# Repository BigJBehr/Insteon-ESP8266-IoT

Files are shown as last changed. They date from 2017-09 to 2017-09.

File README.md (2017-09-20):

Insteon ESP8266 Lighting Controller

# Insteon ESP8266 IoT

## Why I did this:
Home automation is a hot topic these days. It covers everything from window and door sensors to WiFi enabled thermostats to remote control of lights and appliances. I use Insteon devices to control some of the lights in my house and a ceiling fan/light in my bedroom. I originally chose Insteon because it is backward compatible with my older X10 devices. With the inclusion of an Insteon Hub, you can install the Insteon app on your Android or IOS device and control your Insteon devices with your phone or tablet. Insteon is also compatible with the Amazon Echo Dot, a.k.a Alexa. With Insteon and Alexa you can issue voice commands to control your Insteon devices. Very cool. So why would you need yet another way to control your Insteon devices ? The reasons are that Alexa is expensive and does not always work! Your local Amazon Echo recognizes the key phrase “Alexa” and then uses your Internet connection to forward your voice command to an Amazon server for processing. The reply is a digital command sequence that your Alexa forwards to the Insteon Hub. The Insteon Hub then performs the magic. Sometimes Alexa tells me that my Insteon Hub cannot be found or that she is having trouble connecting to the Amazon servers. The end result is that my voice commands do not work. So I have to find my phone or a tablet, wait for it to boot up and then issue the command using the Insteon app. This can be a hassle if you just got into bed and want to turn off the light. You have to get back up and locate an Android device. Ugh.

It would be so much nicer if you had a simple WiFi device with switches that could be programmed to turn on/off your Insteon devices on your bedside table. It would also be great if said device did not rely on having to send messages over the Internet to remote servers to send commands to your local Insteon Hub. This is exactly what I have designed. A simple, low cost, ESP8266 powered IoT device that sends commands to your Insteon Hub, using your local WiFi and wired network. Internet is not required and no outside servers are used.
I designed my Insteon Switch Box to have up to eight pushbutton switches. Each switch can be programmed to turn on or off one Insteon device or scene. A switch may also be programmed to read the state of an Insteon device and then issue a command to change the state. The result is one switch that with one press turns on an Insteon device and a second press turns off the same device. I use an Insteon Fanlinc device to control a ceiling fan in my bedroom. A Fanlinc has two sections. One section controls the light and the other controls the fan. The fan can have three speeds and the light is dimmable. Alexa cannot work directly with an Insteon Fanlinc. In order to use a Fanlinc with Alexa you must create scenes. One scene for the light and one scene for each of the fan speeds. Because scenes are either on or off, Alexa cannot dim the Fanlinc’s light. My Insteon Switch box can send commands to the Insteon Hub to turn on or off or dim the Fanlinc’s light and to control the fan without the need for scenes. This is an improvement over what Alexa can do. My Insteon Switch box was not designed to control a thermostat or listen for door or window sensors. However, with Insteon On/Off plug-in modules that use a relay to turn on/off the plugged in object, it is possible to control drapes or a coffee maker, toaster or electric kettle. You merely have to press a button when you get out of bed. When you exit the shower, your coffee will be ready. All without waking up your mate by talking to Alexa.

## What You will Need:
-	Any ESP8266-12 module or board with an ESP8266-12 module on it. 
-	USB-to-Serial bridge with RTS and DTR unless the ESP8266 board has it built-in.
-	5V, 2A power supply.
-	Power Jack that mates with the power supply.
-	Eight 10K resisters
-	Eight Pushbutton Switches
-	Custom Circuit Board or hand-wired circuit board
-	See individual Bills of Materials for complete parts list.

### Software apps and online services:
-	Arduino IDE, version 1.8.0 or higher
-	ESP8266 Plug-in for Arduino
-	Optional, OpenSCAD

### Hand tools and fabrication machines:
-	Soldering iron
-	Solder, preferably with no clean flux
-	Diagonal cutters
-	Screwdriver
-	Optional, 3D printer

### The Files
- Insteon
  - This folder has the ESP8266 Arduino source code for this project.
- EagleInsteonBoard.zip
  - Zip archive with all the files required to have your own custom circuit boards made.
- Schematic.pdf
  - Pdf version of the Eagle schematic of my custom circuit board.
- 3D Printed Parts
  - This folder contains the OpenScad source file and .stl files for 3D printing all of the case parts.
- Insteon ESP8266 IoT.pdf
  - Pdf file about this project. It has pictures of my custom circuit board, BOMs for each build and detailed information on what to change in the source code to configure it for your Insteon devices and home network.

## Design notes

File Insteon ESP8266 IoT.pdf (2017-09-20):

Insteon ESP8266 IoT
What You will Need:
Any ESP8266-12 module or board with an ESP8266-12 module on it.
USB-to-Serial bridge with RTS and DTR unless the ESP8266 board has it built-in.
5V, 2A power supply.
Power Jack that mates with the power supply.
Eight 10K resisters
Eight Pushbutton Switches
Custom Circuit Board or hand-wired circuit board
See individual Bills of Materials for complete parts list.

Software apps and online services:
Arduino IDE, version 1.8.0 or higher
ESP8266 Plug-in for Arduino
Optional, OpenSCAD

Hand tools and fabrication machines: Soldering iron
Solder, preferably with no clean flux Diagonal cutters
Screwdriver
Optional, 3D printer

Why I did this:
Home automation is a hot topic these days. It covers everything from window and door sensors to WiFi enabled thermostats to remote control of lights and appliances. I use Insteon devices to control some of the lights in my house and a ceiling fan/light in my bedroom. I originally chose Insteon because it is backward compatible with my older X10 devices. With the inclusion of an Insteon Hub, you can install the Insteon app on your Android or IOS device and control your Insteon devices with your phone or tablet. Insteon is also compatible with the Amazon Echo Dot, a.k.a Alexa. With Insteon and Alexa you can issue voice commands to control your Insteon devices. Very cool. So why would you need yet another way to control your Insteon devices ? The reasons are that Alexa is expensive and does not always work! Your local Amazon Echo recognizes the key phrase “Alexa” and then uses your Internet connection to forward your voice command to an Amazon server for processing. The reply is a digital command sequence that your Alexa forwards to the Insteon Hub. The Insteon Hub then performs the magic. Sometimes Alexa tells me that my Insteon Hub cannot be found or that she is having trouble connecting to the Amazon servers. The end result is that my voice commands do not work. So I have to find my phone or a tablet, wait for it to boot up and then issue the command using the Insteon app. This can be a hassle if you just got into bed and want to turn off the light. You have to get back up and locate an Android device. Ugh.

It would be so much nicer if you had a simple WiFi device with switches that could be programmed to turn on/off your Insteon devices on your bedside table. It would also be great if said device did not rely on having to send messages over the Internet to remote servers to send commands to your local Insteon Hub. This is exactly what I have designed. A simple, low cost, ESP8266 powered IoT device that sends commands to your Insteon Hub, using your local WiFi and wired network. Internet is not required and no outside servers are used.

I designed my Insteon Switch Box to have up to eight pushbutton switches. Each switch can be programmed to turn on or off one Insteon device or scene. A switch may also be programmed to read the state of an Insteon device and then issue a command to change the state. The result is one switch that with one press turns on an Insteon device and a second press turns off the same device. I use an Insteon Fanlinc device to control a ceiling fan in my bedroom. A Fanlinc has two sections. One section controls the light and the other controls the fan. The fan can have three speeds and the light is dimmable. Alexa cannot work directly with an Insteon Fanlinc. In order to use a Fanlinc with Alexa you must create scenes. One scene for the light and one scene for each of the fan speeds. Because scenes are either on or off, Alexa cannot dim the Fanlinc’s light. My Insteon Switch box can send commands to the Insteon Hub to turn on or off or dim the Fanlinc’s light and to control the fan without the need for scenes. This is an improvement over what Alexa can do. My Insteon Switch box was not designed to control a thermostat or listen for door or window sensors. However, with Insteon On/Off plug-in modules that use a relay to turn on/off the plugged in object, it is possible to control drapes or a coffee maker, toaster or electric kettle. You merely have to press a button when you get out of bed. When you exit the shower, your coffee will be ready. All without waking up your mate by talking to Alexa.

The remainder of this document will detail how to build one of these for yourself and how to configure the software so it will work with your Insteon devices. There is also some small lessons in writing ‘C’ code.

How to build one:
I designed a custom PCB for this project. All the files can be downloaded from https://github.com/BigJBehr/Insteon-ESP8266-IoT. There is a pdf of the schematic and Eagle files to make your own circuit board. If you have worked with the ESP8266 then you are aware that it comes in a dizzying array of forms. From bare modules that require support circuits to breadboard friendly boards with all required support circuits and a USB-to-serial bridge. The board that I designed for this project can accept the ESP8266 in four different forms and has pads to add any support circuits required by the ESP8266 you chose to use. My board does not have a USB-to-Serial bridge on board. If that is required there is a header to attach one. Your USB-to-Serial bridge must have RTS and DTR in order to program the ESP8266. Of course, you are free to handwire the switches to the ESP8266-12 of your choice. The four ESP8266 forms supported by my board are;

ESP8266-12 module

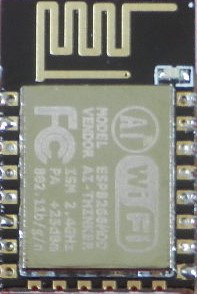
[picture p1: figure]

The least expensive ESP8266, but requires the most support. My board has pads for a 3.3V regulator and the ‘auto-reset’ circuit used for programming. You will need a USB-to-Serial bridge with RTS and DTR.

Bill of Materials
Quantity | Reference Numbers | Description
1 | SOC1 | ESP8266-12 module
8 | SW1 – SW8 | Pushbutton switches, four leads, 7x4mm spacing
10 | R1, R3 – R11 | 10K , surface mount resistors, 1206
1 | R2 | 470 , surface mount resistor, 1206
2 | R12, R13 | 1K , surface mount resistors, 1206
2 | R14, R15 | 4.7K , surface mount resistors, 1206
1 | VR1 | AS1117-3.3V regulator, SOT-223
2 | Q1, Q2 | MMBT2222A transistor, TO-23
2 | C1, C2 | 10uf, 16V, Tantalum, capacitors, 1206, size A
1 | J5 | 3 pin right angle, male header

1 | J8 | 6 pin right angle, male header

ESP8266-12 Witty Board

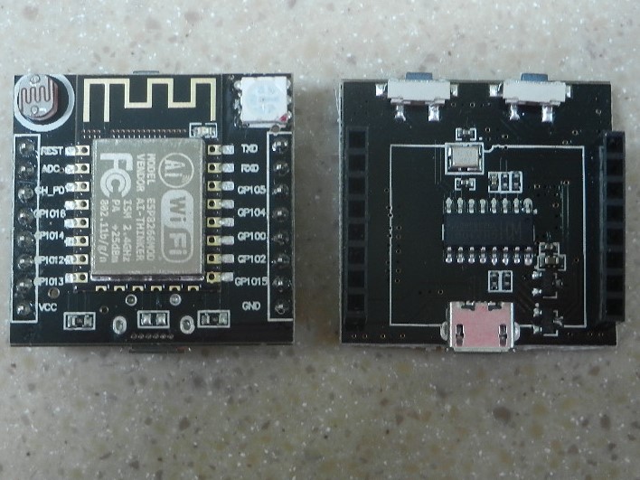
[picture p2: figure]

This is actually two boards that mate together. If you use this you will only need the top board that actually contains the ESP8266 and the 3.3V regulator. You can program the ESP8266 while attached to the lower board it came with and then mount it to your board or you can program it in place by using jumpers to connect to the lower board or adding the ‘auto-reset’ circuit and using a USB-to-Serial bridge. Do not throw away the lower board. You can always use it as a USB-to-Serial bridge. Just be aware that it provides 5V signals, not 3.3V signals like most USB-to-Serial bridges. The Witty board does not require the pulldowns on GPIO15 and the analog input as these parts are on the Witty board. You can also eliminate the pullups on Reset and GPIO0 (SW7) for the same reason.

Bill of Materials (BOM)
Quantity | Reference Numbers | Description
1 Witty ESP8266-12 board
2 | J1, J2 | 8 pin female socket headers, optional
8 | SW1 – SW8 | Pushbutton switches, four leads, 7x4mm spacing
10 | R3 – R9, R11 | 10K , surface mount resistors, 1206
2 | R12, R13 | 1K , surface mount resistors, 1206
1 | VR1 | AS1117-3.3V regulator, SOT-223
2 | Q1, Q2 | MMBT2222A transistor, TO-23
2 | C1, C2 | 10uf, 16V, Tantalum, capacitors, 1206, size A
1 | J5 | 3 pin right angle, male header
1 | J8 | 6 pin right angle, male header

Note:
If you do not intend to program the ESP8266 Witty board in circuit then you can eliminate; Q1, Q2, J8, R12 and R13. If you solder the Witty board in place then use the holes for J1 and J2 and you can eliminate J1 & J2. Power can be applied using the micro USB connector on the bottom of the Witty board with the ESP8266 or can be wired to J5 or J8. You can eliminate J5 if you intend to use J8 or the micro USB connector.

GeekCreit, DOIT, ESP8266-12 DevKit board

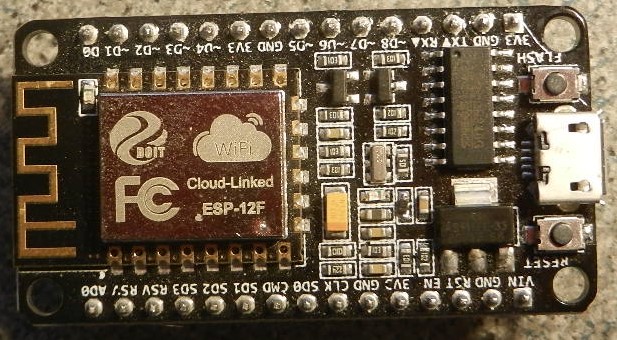
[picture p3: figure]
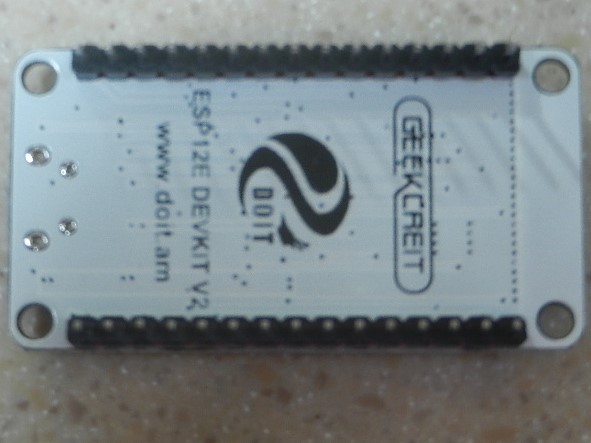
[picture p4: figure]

This is a single board that has everything onboard to program the ESP8266. There is a micro USB connector and an onboard USB-to-Serial bridge. No support circuits are required to use this board. Boards like this are also known as NodeMcu boards. These boards come in two widths, wide and narrow. My circuit board is laid out to accept the narrower boards. Look for one that has pin spacing of 0.9 inches. The original NodeMcu boards have 1.2 inch spacing and will not fit.

Bill of Materials
Quantity | Reference Numbers | Description
1 GeekCreit, DoIt ESP8266-12 board
2 | J3, J4 | 15 pin female socket headers, optional
8 | SW1 – SW8 | Pushbutton switches, four leads, 7x4mm spacing
10 | R3 – R9, R11 | 10K , surface mount resistors, 1206
1 | J5 | 3 pin right angle, male header, optional

Note:
If you solder the GeekCreit, DoIt board in place then you can eliminate J3 & J4. You can power the system using the micro USB connector on the GeekCreit board or using J5.

Sparkfun ESP8266 Thing Dev board

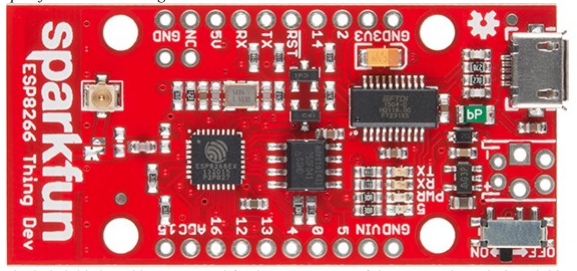
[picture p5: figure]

I included this board because Sparkfun is a co-sponsor of the contest that I designed this project for. Unfortunately, the sponsors did not like my idea well enough to provide me with a free Sparkfun ESP8266 Thing Dev board. The Sparkfun board has all of the required support circuits already on it, including the USB-to-Serial bridge.

Bill of Materials
Quantity | Reference Numbers | Description
1 Sparkfun ESP8266 Thing Dev board
2 | J6, J7 | 10 pin female socket headers, optional
2 10 pin male headers
8 | SW1 – SW8 | Pushbutton switches, four leads, 7x4mm spacing
10 | R3 – R9, R11 | 10K , surface mount resistors, 1206
1 | J5 | 3 pin right angle, male header, optional

Note:
If you solder the Sparkfun ESP8266 Thing Dev board in place then you can eliminate J6 & J7. You can power the system using the micro USB connector on the Sparkfun ESP8266 Thing Dev board or using J5. The two 10 pin male headers are soldered to the bottom of the Sparkfun ESP8266 Thing Dev board (they should come with the board).

My custom circuit board has places to mount eight pushbutton switches and provides pads for a 10K pullup for each switch. The pullups are required due to the ESP8266 not having internal pullups on the GPIO pins. All of the GPIO pins except the analog pin, GPIO15, Tx and Rx are used for the pushbutton switches. The analog input and GPIO15 have pulldowns wired to them and Rx has a pullup. No pins are left floating. Always a good thing to do. Of course, you are free to handwire your own board. Then you can use whatever ESP8266 board that you have available. You can leave out the 3.3V regulator and ‘auto-reset’ circuits if the board you use does not require them. Mount the ESP8266 board of your choice with the antenna oriented as indicated on the circuit board. Use the set of holes or pads that fit the board that you are using. The mounting holes in the corners are sized to accept 3mm, 4-40 or 6-32 hardware.

I prefer to assemble boards from the lowest height components to the tallest components. Therefore I usually start with the surface mount resistors, transistors, capacitors and regulators. Then comes the ESP8266 module. Last would be the headers and sockets. I built my boards with right angle male headers facing inward to reduce the overall height and length of the finished board. The pushbutton switches are intended to be mounted on the bottom side of the board. I have included pictures of assembled boards with different ESP8266 boards attached. The ESP8266 boards were not soldered down. They are in place to show location and orientation. They were paid scale for their modeling work.

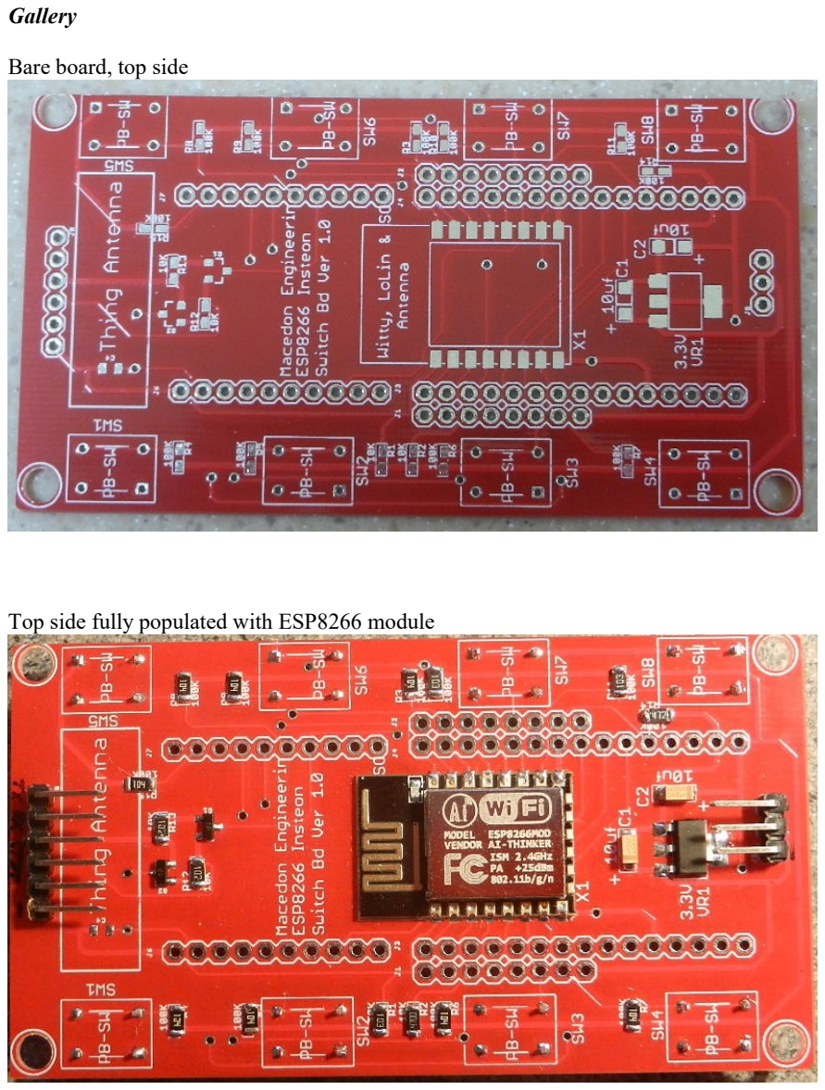
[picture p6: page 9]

Gallery

Bare board, top side

Top side fully populated with ESP8266 module

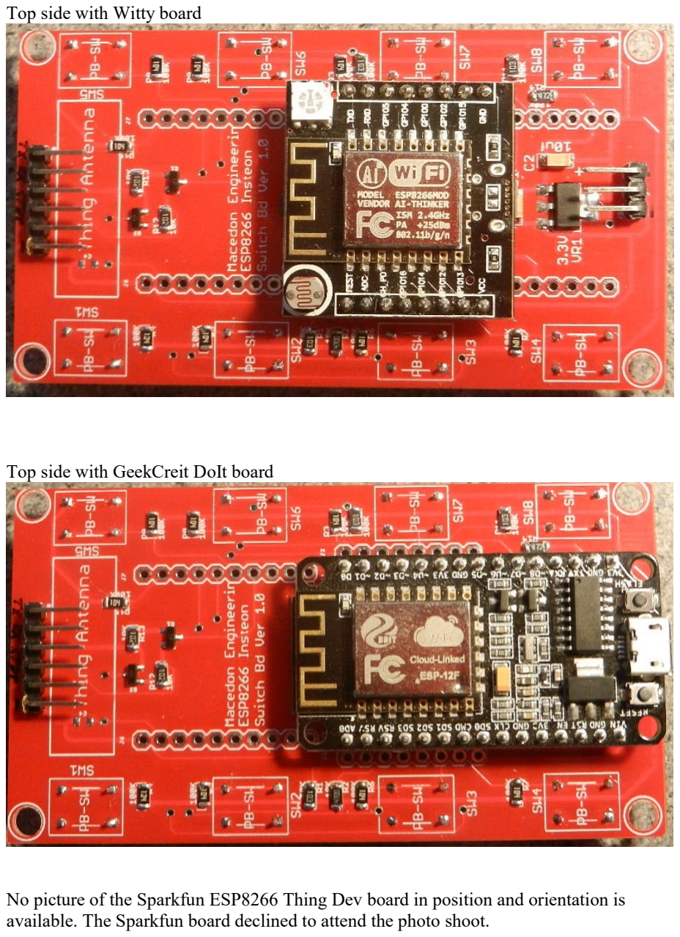
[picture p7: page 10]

Top side with Witty board

Top side with GeekCreit DoIt board

No picture of the Sparkfun ESP8266 Thing Dev board in position and orientation is available. The Sparkfun board declined to attend the photo shoot.

Bottom populated with pushbutton switches

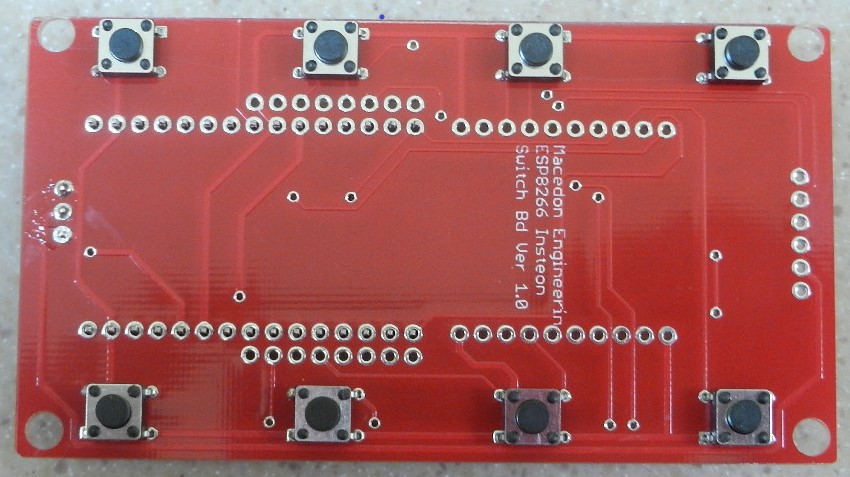
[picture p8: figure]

How it works:
The ESP8266 at the heart of the Insteon Switch box debounces the switches and looks for a switch pressed. When it detects that a switch has been pressed it looks up what has been programmed for that switch to do and then creates a control message for the Insteon Hub. The message is sent to the Hub, which converts the message into a control command and forwards it to the targeted Insteon device. Any replies from the targeted Insteon device are sent back to the Hub and the Hub then sends the reply back to ESP8266 using the Insteon Hub message format. The reply is parsed and the relevant data is stored. The Internet is not used. Everything is done over your local network.

How to configure the firmware for your Insteon devices:

There are a lot of websites providing detailed instructions on how to setup the Arduino IDE, compile a program and upload it as well as how to install the ESP8266 plug-in. I am not going to repeat that information here. Just Google it.

I have defined a ‘C’ structure named TSwitch, that contains all the information needed for one pushbutton switch. The structure is as follows;

Typedef struct {
byte | pin; | // GPIO pin number that the switch is wired to
int16_t | state; | // the last known state of the Insteon device
uint32_t | debounce; | // switch debouncer bit array
ActionPtr | action; | // pointer to the action function assigned to the switch
char | *devId; | // pointer to the device ID string of the Insteon device

char | *cmd2; | // pointer to the cmd2 string to send for status requests
char | *cmdOn; | // pointer to the on command string
char | *cmdOff; | // pointer to the off command string
} TSwitch;

An array of eight TSwitch structures is used to hold the information for each switch. If you build one of these for yourself you will need to replace the data in some of the fields of the TSwitch structure for how you would like your switches to work and for the Insteon devices and scenes that you want to control. Each Insteon device has a label on it with its unique Insteon ID. I have a series of statements where I define a meaningful to me name for each Insteon device ID. You can find these in the code as;

#define Kitchen “339EFC”

Kitchen is the meaningful name, “339EFC” is the Insteon device ID.

The #define makes this a ‘C’ preprocessor macro. This means that wherever Kitchen is found in the source code the ‘C’ preprocessor will substitute “339EFC”. “339EFC” is the Insteon ID string converted from the dot format on the label (33.9E.FC). I also have some #define statements that define the scene Ids that I might use. Scene Ids are two digit number strings such as “10” for scene number ten or “07” for scene number seven. You can get the scene numbers and Insteon Ids from the Insteon app on your phone or tablet. There are a bunch of #define statements that define the command strings that can be used. All of the command strings are prefixed with Cmd followed by a descriptive name. For example;

#define CmdOn | “11FF” | // command to turn on a device to full brightness

You will need to change the #define statements that define the Insteon Ids and scene numbers for the devices and scenes that you use. The #define statements for the commands should not be changed.

There is a statement; #define PINMASK 0x00000FFF
This statement defines the number of bits that are used to debounce a pushbutton switch. If the buttons that you use have more than 12mS of bounce then you should increase the number of bits in the mask. If you use all 32 bits and require more time then you should change the 1mS delay in the main loop to two or more milliseconds and decrease the number of bits accordingly. Twelve bits and 1mS should be adequate for most pushbutton switches.

As I stated earlier, there is an array of eight TSwitch structures, one for each pushbutton switch. A ‘C’ style initializer is defined for the array. This means that a table of entries for initializing the TSwitch array is defined in Flash ROM. The table is copied to the RAM TSwitch array automatically when the program starts up. You have to edit this initializer table to configure what you want the pushbutton switches to do and what Insteon devices/scenes each pushbutton will work with. The initializer is of the form;

{SWx, UnknownState, 0, action-to-take, device Id/scene, Cmd2, CmdOn, Cmdoff}

The individual initializers are separated by a comma (‘,’) and the whole group of eight initializers is wrapped in a pair of curly braces (‘{‘ ‘}’). This is just the way that the ‘C’ programming language does things. There must be one initializer for each entry in the array or the compiler will complain. If you leave out a curly brace or a comma the compiler will complain. That is just how compilers are, always complaining that you left something out. The pushbutton switches are arranged in the same numerical order that they are in the hardware, so SW1 in the software is SW1 on the board, is array[0]. I advise against changing the order of the switches. The first three entries in the initializer should remain unchanged. They represent the GPIO pin the pushbutton switch is wired to, the state of the Insteon device (unknown), and the state of the debouncer. The forth value is a pointer to the ‘C’ function that will be called when the switch is pressed. There are a number of action functions defined. You should choose the one that does what you want the pushbutton to do. If you are not using the pushbutton then set the action field to NULL (all caps). This will tell the code to ignore this pushbutton. The action functions are; actionToggle, actionOn, actionOff, actionFanSpeed.

actionToggle reads the current state of the Insteon device whose ID is in the devId field of the associated TSwitch structure and then issues a command to change to the opposite state. Use actionToggle to create a button that will turn something on when pressed and turn it off when pressed again. The cmdOn and cmdOff fields of the associated TSwitch structure are used to get the on and off commands. If the Insteon device being used is dimmable then you could use the CmdHalf command in place of CmdOn. This would cause the light to toggle between half brightness and off.

actionOn simply sends whatever command is in the cmdOn field of the associated TSwitch structure to the Insteon device whose ID is in the devId field of the associated TSwitch structure. Use actionOn when you want a pushbutton to turn an Insteon device on. If you replace the CmdOn with CmdHalf and the Insteon device is dimmable then it would come on at half brightness. If you replaced CmdOn with CmdBrighten then each time you pressed the button the brightness would increase until full brightness is achieved.

actionOff simply sends whatever command is in the cmdOff field of the associated TSwitch structure to the Insteon device whose ID is in the devId field of the associated TSwitch structure. Use actionOff when you want a pushbutton to turn an Insteon device off. If your Insteon device is dimmable then you can substitute CmdHalf to reduce the brightness to half or CmdDim to reduce the brightness in steps until it was fully off. If you used CmdHalf then you will need to use another button to actually turn the device off.

actionFanSpeed is unique in that it reads the current fan speed setting and then ups the speed to the next fan speed setting. The cycle is; off -> low -> medium -> high -> off. ActionFanSpeed does not use the cmdOn and cmdOff fields.

The next field in the initializer (devId) is a ‘C’ style character string that contains the Insteon Id of the device or the scene number that you want to control. I previously talked about the #define values that I setup to provide meaningful names (aliases) for my Insteon Ids. Here I use those names. You should do the same, making meaningful names for your Insteon Ids or simply put the Insteon Id string here as “123456”. Keep In mind that an Insteon device Id will have six characters while a scene number will have two digits (“07”).

The next field in the initializer is the cmd2 field. This field is normally initialized with the value; Cmd2Lights. Change this initializer to Cmd2Fans if you are setting up a pushbutton to work with the fans section of a Fanlinc Insteon device.

The last two fields of the initializer are the cmdOn and cmdOff fields. These fields contain pointers to the defined Insteon command strings. Typically you would put CmdOn in cmdOn and CmdOff in cmdOff. You can put any of the CmdXxxx values in these fields, although CmdStatus, Cmd2Lights and Cmd2Fans should not be used.

One thing to note here, I defined a simple command for CmdOn that turns a light on full brightness. If you have dimmable light controller you can define commands that will turn on your light to a preset brightness. The light on command is “11” the “FF” in the second byte is the brightness level. CmdHalf is defined as “117F”, it will turn your light on to half brightness. You can use any value from “01” to “FF” for the brightness level. Keep in mind that if you send a command for partial brightness to an Insteon device that is not dimmable or a scene then it will turn on at full brightness.

The CmdOnFast and CmdOffFast commands are be used to override the ramp up and ramp down setting in the Insteon app and force the device to full brightness or off without ramping. I do not use these commands because all my dimmable Insteon devices use the default ramping.

There are also #define statements for;
SSID | – change to the ssid of your network
PASSKEY | – change to the WiFi WPA passkey for your network,
HUBUSER | – change to the user ID for your Insteon Hub
HUBPASSWORD | – change to the password for your Insteon Hub
HUBIP | – change to the IP address of your Insteon Hub
HTTPPORT | – you can change this if you change the port number that your
Insteon Hub uses, otherwise this is the default value.

That’s it. Make the changes to the source code, recompile and download it to your ESP8266. I hope that you find it to be a useful addition to how you control your Insteon devices. If you have any problems building one for yourself or need help with the code you may contact me through HacksterIO. I will endeavor to provide as much help as I can.

I bought ten of these boards from a Chinese PCB manufacturer. I built up three. I have seven boards that are unused bare boards. If you would like one, tell me why you deserve a free board and maybe I will send you one.

I have included the Eagle files the board was made from in the GitHub archive. Feel free to have your own boards made. Ten boards cost around $15-$20.00 US and take about 3-4 weeks to arrive in the USA.

I have also designed a 3D printable case for my project board. The design was done using OpenSCAD. I have include the OpenSCAD source code and the .stl file if you would like to print your own. If you design your own case, I would be interested in seeing what you came up with. Send me a picture of the case you designed. My case uses four 3x6mm screws to hold the board to the top of the case. In the OpenSCAD source file there is a variable named SHD that can be changed to make the hole in the bosses correct for other screw sizes. Always use a ¼ inch or 6mm long screw to avoid coming through the top of the case. After printing the parts, clean off all of the easy removal pads. Insert the buttons into the holes in the top, wide part should be inside the case. Screw the circuit board to the underside of the top. Add the power jack to the case bottom. Solder wires to the power jack. Either add crimp pins and a header, or use an IDC header or solder the wires in place of J5 on the circuit board. The top just snaps into the bottom. The fit should be tight enough that it will stay put without any glue. Congratulations, pat yourself on the back and break out the Champagne. You are done.

The .stl file is for a case top, bottom, four bullet top buttons and four flat top buttons. It is very easy to modify the source code to print only the top or bottom or to change the number of bullet top & flat top buttons. I commented out the top and bottom parts and printed some buttons using red and white filament. Everything is done in a modular fashion with the lines following the “$fn=50” to the first “module” statement determining what gets printed. “translate” statements are used to reposition the parts. If you only print buttons then change the “translate” statements to move the buttons to the center of your build platform or where ever you want them.

Here are some pictures of the case assembly.

Power plug assembly

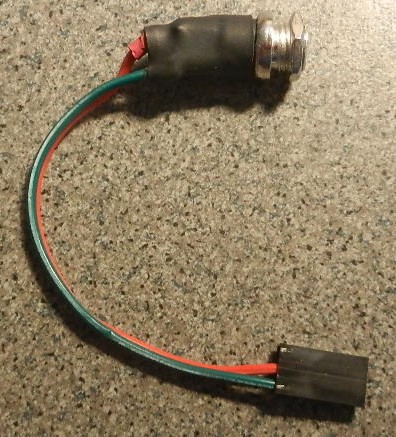
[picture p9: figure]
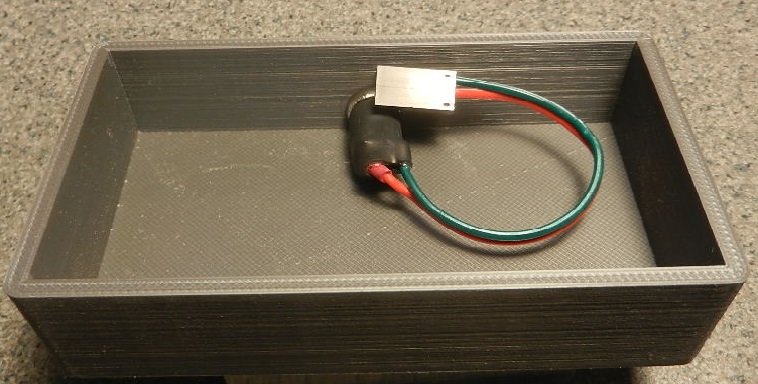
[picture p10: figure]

Case bottom with power plus assembly.

Under side of the case top. Ready for buttons and circuit board.

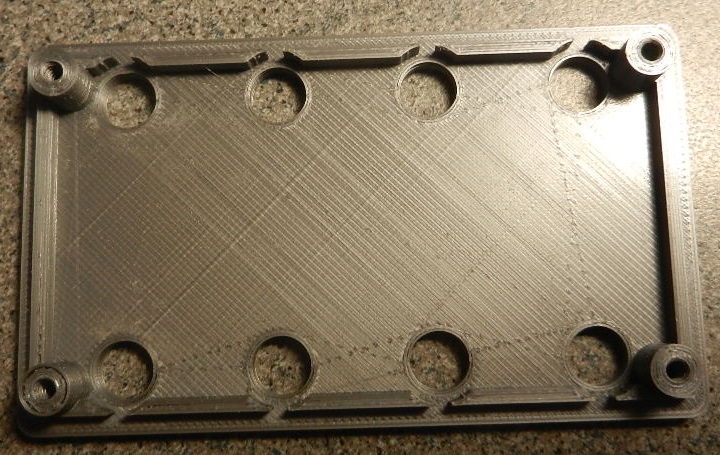
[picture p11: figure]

Case top with buttons inserted. Red buttons are in position for Sw1-Sw3. Notice how the case bottom is used to support the top so that you are not fighting with the buttons.

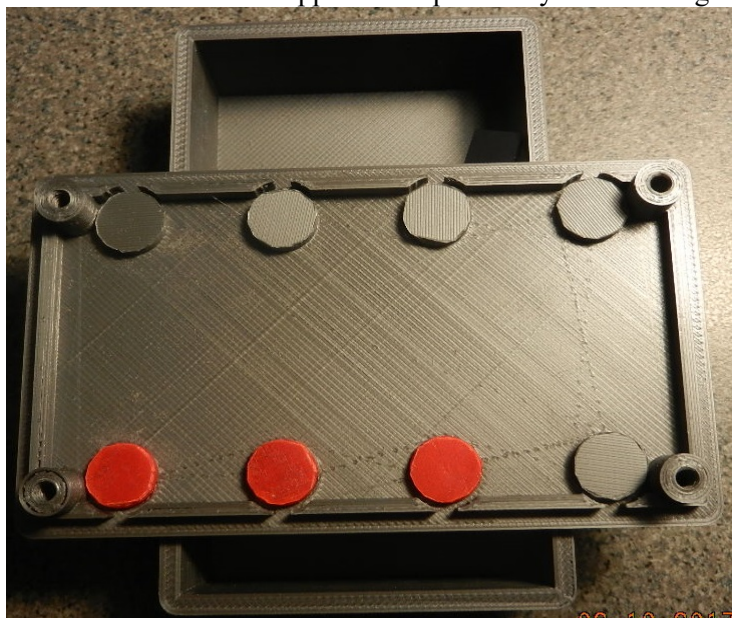
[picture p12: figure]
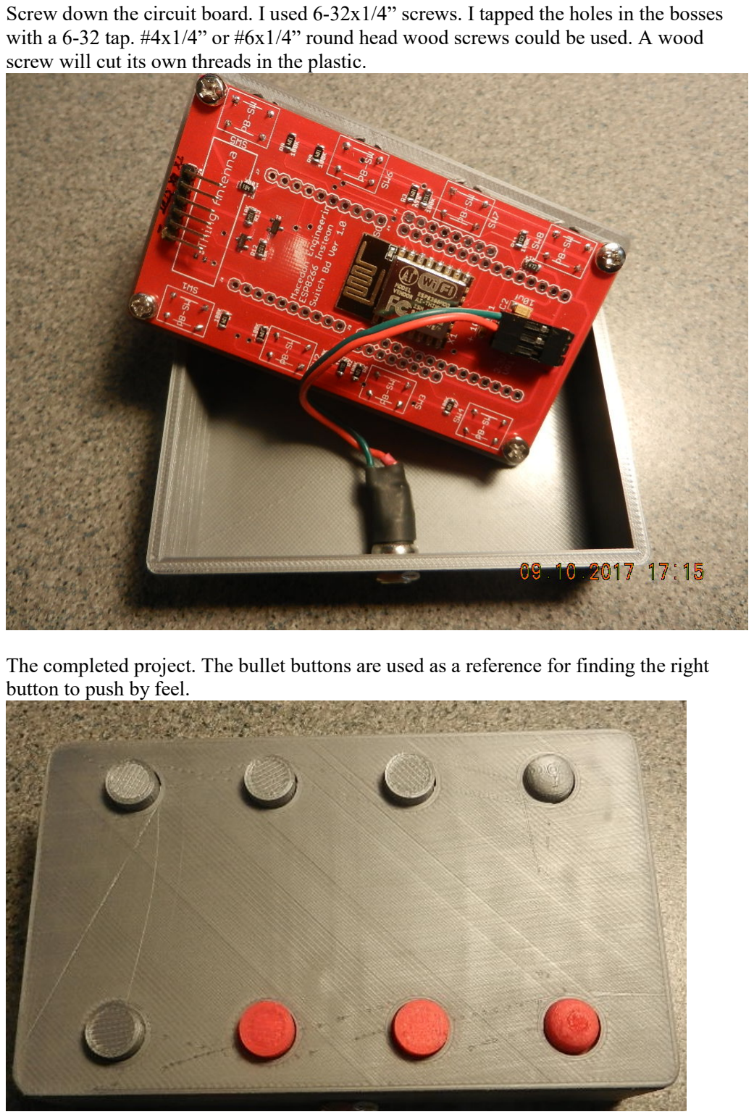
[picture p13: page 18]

Screw down the circuit board. I used 6-32x1/4” screws. I tapped the holes in the bosses with a 6-32 tap. #4x1/4” or #6x1/4” round head wood screws could be used. A wood screw will cut its own threads in the plastic.

The completed project. The bullet buttons are used as a reference for finding the right button to push by feel.

While I was developing the code I had to search the Internet for tidbits on the Insteon protocol. I found that the Insteon Hub commands are not limited to just controlling Insteon devices. It is also possible to send commands to the Hub to control X10 devices. I was not interested in controlling X10 devices so I did not include any code for doing that. Insteon commands can also control an Insteon thermostat. I do not have an Insteon thermostat so I was not interested in controlling one. Like they say, these are exercises best left to the reader.

OpenSCAD is a free program that allows you to design 3D models using a simple programming metaphor.

Arduino IDE is a free program that allows you to write ‘C’ style code, compile and upload it to a variety of microcontrollers. It is based on the Programming paradigm of coding.

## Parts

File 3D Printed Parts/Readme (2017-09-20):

InsteonSwitchBox.scad - OpenSCAD source code for all 3D printed parts

Complete.stl          - STL file to print all parts required
Top.stl               - STL file to print just the case top
Bottom.stl            - STL file to print just the case bottom
BulletButtons.stl     - STL file to print four bullet buttons
FlatTopButtons.stl    - STL file to print four flat top buttons with no text

If you want to add a single letter to the top of the flat top buttons then you
have to edit InsteonSwitchBox.scad file. 

If you use socket strips to mount your ES8266 board then you have to edit
InsteonSwitchBox.scad file to change the height of the case bottom.

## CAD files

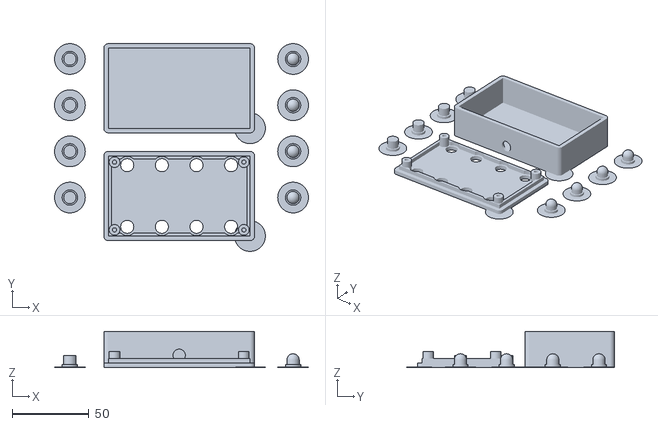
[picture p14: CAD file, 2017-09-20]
3D Printed Parts/Complete.stl
165.0 x 135.0 x 23.5

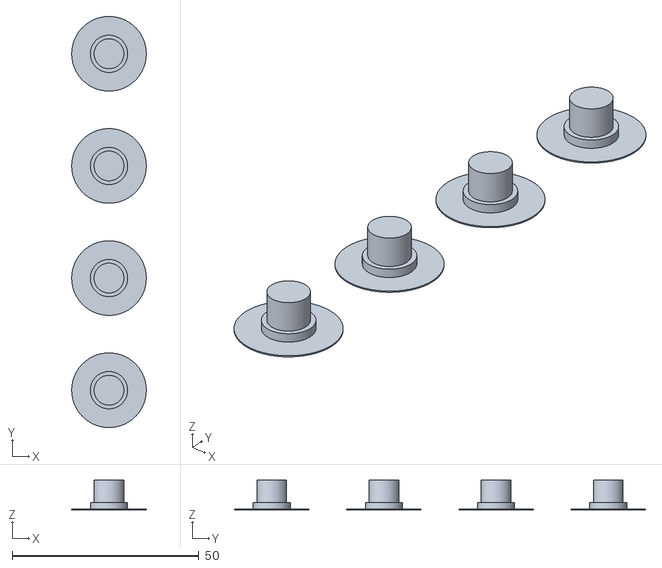
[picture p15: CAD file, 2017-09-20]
3D Printed Parts/FlatTopButtons.stl
20.0 x 110.0 x 8.00

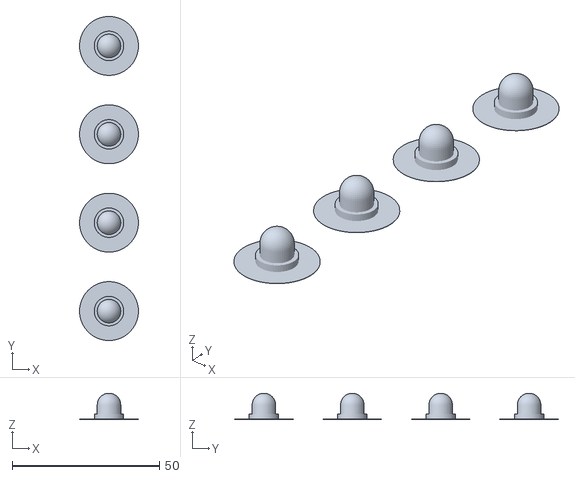
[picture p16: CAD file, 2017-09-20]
3D Printed Parts/BulletButtons.stl
20.0 x 110.0 x 8.99

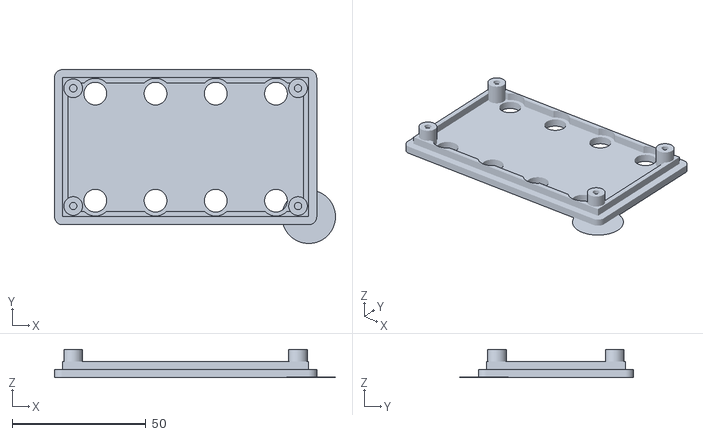
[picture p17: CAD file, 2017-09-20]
3D Printed Parts/CaseTop.stl
105.0 x 65.0 x 10.5

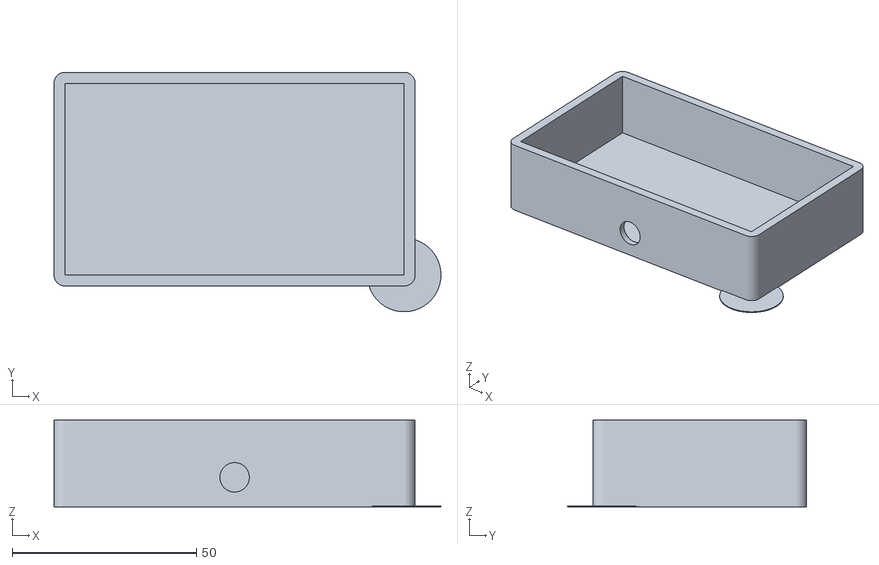
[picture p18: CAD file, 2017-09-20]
3D Printed Parts/CaseBottom.stl
105.0 x 65.0 x 23.5

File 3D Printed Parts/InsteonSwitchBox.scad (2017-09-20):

// Insteon Switch Box
X = 92;
Y = 52;

Floor = 3;          // thickness of the case top and bottom

D = 6;              // diameter of the rounded corners
R = D / 2;

PostD  = 7;         // diameter of board mounting bosses
PostZ  = 7.5;       // height of the board mounting bosses. provides a 0.5mm gap

                    // between the top of a switch and the bottom of a button
// uncomment one and only one of these. this is the size of the hole in the
// board mounting bosses. pick the correct size for the hardware you are using.
//SHD = 1.75;         // correct size for #2 pan tapping screw
//SHD = 2.25;         // correct size for M2.5 pan tapping screw or tap
//SHD = 2.25;         // correct size for 4-40 screw or tap
SHD = 2.75;         // correct size for M3 screw or tap
//SHD = 3;            // correct size for 6-32 screw

JackD = 8;          // barrel jack clearence hole is 8mm

// Floor + JackD is the height of the top of the power jack
// PostZ + 2 is how much the PC board hangs down from the top
// add in 5mm for clearance and jack offset from floor
Z = Floor + JackD + 5 + PostZ;  // minimum height so that board clears power jack

//*****************************************************************************
// if you are using an ESP8266 board that is socketed then un-comment this
//Z = 26;          // extra height to accomodate socket strips
//*****************************************************************************

//*****************************************************************************
// This is the start of the main code that 3D prints all of the parts.
//*****************************************************************************
$fn = 50;

// ***** Here is where all the parts are printed at the same time *****
// Comment out what you do not want to print by placing two slashes ("//") in
// front of the line.

// Prints the case Bottom
Bottom();

// Moves the case top away from the bottom and prints it. Translate uses
// [X, Y, Z] coordinates to move the Top.
translate([0, -70, 0]) Top();

// You will need eight buttons. You can make any combianation of flat top
// or bullet buttons. The default is four flat top and four bullet buttons.
// Translate moves the buttons away from the Bottom, Top and other buttons.
// You can have one letter printed on top of FlatButtons. If you do not want
// a letter then use "" to specifiy no text.

bx = -25;
translate([bx, -15, 0]) FlatButton("");
translate([bx, -45, 0]) FlatButton("");
translate([bx,  15, 0]) FlatButton("");
translate([bx,  45, 0]) FlatButton("");

bbx = 120;
translate([bbx, -15, 0]) BulletButton();
translate([bbx, -45, 0]) BulletButton();
translate([bbx,  15, 0]) BulletButton();
translate([bbx,  45, 0]) BulletButton();

//***** End of the main code *************************************************

// ***** case bottom *****
module Bottom()
{
    translate ([X, 0, 0]) cylinder(d = 20, h = .25);  //  removel tab
    difference()
    {
        Base(Z);
        translate([0, 0, Floor]) cube([X, Y, Z]);
        PowerJack();
    }   // bottom difference
}   //  Bottom


// ***** case top *****
module Top()
{
    translate([X, 0 , 0]) cylinder(d = 20, h = .25);  //  removel tab

    difference()
    {
        union()
        {
            Base(Floor);
            translate([0, 0, Floor]) cube([X, Y, Floor]);
        }
        
        translate([2, 2, Floor]) cube([X -4 , Y - 4, Floor]);
//        translate([0, Y2, 0]) Switches(9);
        Switches(9);
    }   // top difference
    
    // add board hounting bosses
    byh2h = 44;
    bxh2h = 84;

    bxoffset = (X - bxh2h) / 2;
    byoffset = (Y - byh2h) / 2;
    
    translate([bxoffset, byoffset, Floor]) Bosses();
}   //  Top    


module Base(z)
{
    hull()
    {
        cylinder(d = D, h = z);
        translate([X, 0, 0]) cylinder(d = D, h = z);
    }

    translate([0, Y, 0]) hull()
    {
        cylinder(d = D, h = z);
        translate([X, 0, 0]) cylinder(d = D, h = z);
    }
    
    translate([-R, 0, 0]) cube([X + D, Y, z]);
}   //  Base

module Bosses()
{
    difference()
    {
        Posts(PostD);
        Posts(SHD);
    }
}   //  Bosses

module Posts(d)
{
    yh2h = 44;
    xh2h = 84;

    cylinder(d = d, h = PostZ);
    translate([xh2h, 0, 0]) cylinder(d = d, h = PostZ);
    translate([0, yh2h, 0]) cylinder(d = d, h = PostZ);
    translate([xh2h, yh2h, 0]) cylinder(d = d, h = PostZ);
}   //  Posts

module Switches(tc)
{
    xh2h = 22.5;
    yh2h = 40;
    xoffset =  (X - (3 * xh2h)) / 2;
    yoffest =  (Y - yh2h) / 2;
    d = ButtonD + 0.5;
    d1 = d + 3 ;

    translate([xoffset, yoffest, 0])
    {
        cylinder(d = d, h = Floor);
        translate([xh2h, 0, 0]) cylinder(d = d, h = Floor);
        translate([xh2h * 2, 0, 0]) cylinder(d = d, h = Floor);
        translate([xh2h * 3, 0, 0]) cylinder(d = d, h = Floor);

        translate([0, yh2h, 0]) cylinder(d = d, h = Floor);
        translate([xh2h, yh2h, 0]) cylinder(d = d, h = Floor);
        translate([xh2h * 2, yh2h, 0]) cylinder(d = d, h = Floor);
        translate([xh2h * 3, yh2h, 0]) cylinder(d = d, h = Floor);
    }

    translate([xoffset, yoffest, Floor])
    {
        cylinder(d = d1, h = Floor);
        translate([xh2h, 0, 0]) cylinder(d = d1, h = Floor);
        translate([xh2h * 2, 0, 0]) cylinder(d = d1, h = Floor);
        translate([xh2h * 3, 0, 0]) cylinder(d = d1, h = Floor);

        translate([0, yh2h, 0]) cylinder(d = d1, h = Floor);
        translate([xh2h, yh2h, 0]) cylinder(d = d1, h = Floor);
        translate([xh2h * 2, yh2h, 0]) cylinder(d = d1, h = Floor);
        translate([xh2h * 3, yh2h, 0]) cylinder(d = d1, h = Floor);
    }

}   //  Switches

// The default position of the power jack is in the middle of one of the long sides.
// If the height of the box walls exceeds 25mm then the power jack is centered on one
// of the short sides. This prevents interference with the ESP8266 board.
module PowerJack()
{
    d = JackD;      // barrel clearence is 8mm
    d1 = d + 2;
    
    if (Z < 25)
    {
        translate([X / 2, 0, Floor + (d1 / 2)]) rotate([90, 0, 0]) cylinder(d = d, h = 5);
        translate([X / 2, 0, Floor + (d1 / 2)]) rotate([90, 0, 0]) cylinder(d = d1, h = 1);
    }
    else
    {
        translate([0, Y / 2, Floor + (d1 / 2)]) rotate([0, -90, 0]) cylinder(d = d, h = 5);
        translate([0, Y / 2, Floor + (d1 / 2)]) rotate([0, -90, 0]) cylinder(d = d1, h = 1);
    }
}   //  PowerJack

ButtonHeight = Floor + 2;
ButtonD = 8;

module FlatButton(text)
{
    Button();
    translate([0, 0, ButtonHeight]) cylinder(d = ButtonD, h = 3);
    
    translate([0, -2.5, ButtonHeight + 3])
    {
        linear_extrude(height = 1) text(text, font = "Liberation Sans", size = 5, , halign = "center");
    }
}   //  BulletButton

module BulletButton()
{
    d = 8;
    
    Button();
    translate([0, 0, ButtonHeight]) sphere(d = d);
}   //  BulletButton

module Button()
{
    d1 = ButtonD + 2;
    
    cylinder(d = d1, h = 2);
    cylinder(d = ButtonD, h = ButtonHeight);
    
    cylinder(d = 20, h = .25);  //  removel tab
}   //  Button

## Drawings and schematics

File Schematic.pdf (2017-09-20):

# SW1 PB-SW

# 4 SW2 PB-SW

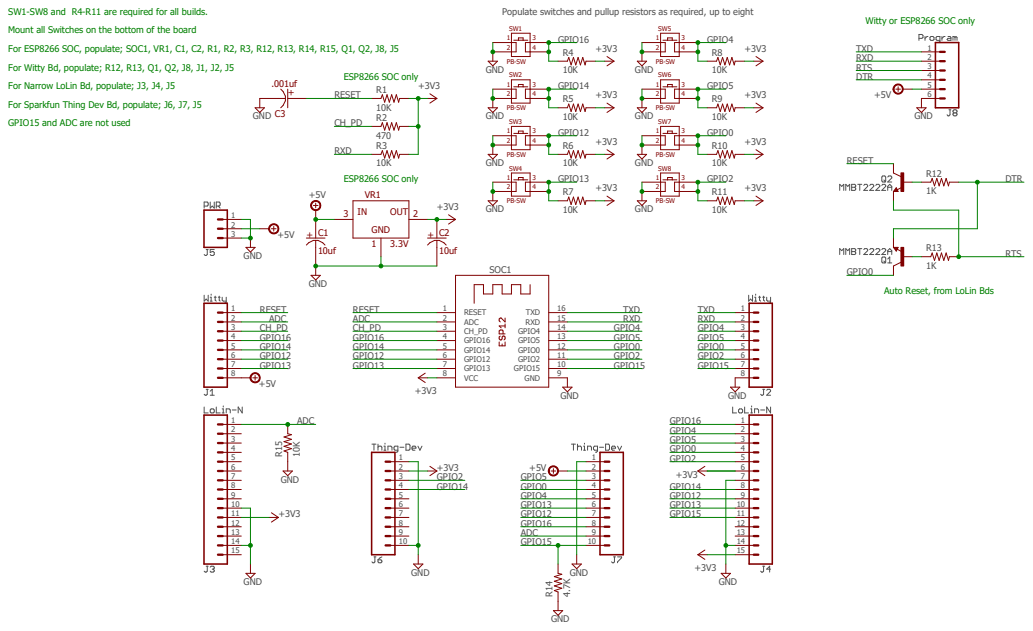
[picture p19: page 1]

SW1-SW8 and R4-R11 are required for all builds.
Mount all Switches on the bottom of the board
For ESP8266 SOC, populate; SOC1, VR1, C1, C2, R1, R2, R3, R12, R13, R14, R15, Q1, Q2, J8, J5
For Witty Bd, populate; R12, R13, Q1, Q2, J8, J1, J2, J5
For Narrow LoLin Bd, populate; J3, J4, J5
For Sparkfun Thing Dev Bd, populate; J6, J7, J5
GPIO15 and ADC are not used

Populate switches and pullup resistors as required, up to eight

Witty or ESP8266 SOC only

Auto Reset, from LoLin Bds

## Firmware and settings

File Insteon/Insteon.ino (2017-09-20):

// Project:   ESP8266 IoT Contest Entry
// Author:    James R. Behrens
// Compiler:  Arduino IDE Ver 1.8.0 with ESP8266 plug-in

// ESP8266 Contest entry. Uses an ESP8266 to send commands to an Insteon Hub to control Insteon
// devices and/or scenes. Does not use MQTT to access an outside server to send commans to your
// Insteon hub. All communications is done using your local network. An Internet connection
// is not required.

// HTTP Client for ESP8266 to control Insteon Devices
// This should work on any ESP8266 based board.

// This has been tested and works with the following Insteon devices
// Fanlinc                          - 2475F    - fan and light controller, fan uses extended format commands
// On/Off Module                    - 2635-232 - relay module that can control lights and motors (plug in)
// SwitchLinc Remote Control Dimmer - 2477D    - works with CFL, incandesant and LED lights (in wall)
// LED Light Bulb                   - 2672-222 - socket must be always on
// Insteon Hub                      - 2245-222 - Alexa compatible, Insteon & X10 protocols

#include <ESP8266HTTPClient.h>
#include <ESP8266WiFi.h>
#include <Arduino.h>

// uncomment this to enable debug messages
//#define DEBUG

// ESP8266 module on Insteon Switch board
// In Arduino Board Manager, Select the following;
// Arduino Board: "WeMos D1 R2 & mini"
// CPU Frequency: "80MHz"
// Flash Size:    "4M(3M SPIFFS)"
// Upload Speed:  "921600"


// ***** Change these for your WiFi SSID and passkey *****
#define SSID    "yourssid"
#define PASSKEY "yourpasskey"

// Change these for the User name, Password, IP address and HTTP Port of your Insteon Hub
#define HUBUSER       "user"
#define HUBPASSWORD   "password"
#define HUBIP         "192.168.1.100"
#define HTTPPORT      "25105"       // default

// Insteon IDs of all of my devices I want to control. The ID is in Hex ASCII.
// These should be replaced with the IDs and names of your devicess. The Insteon
// ID is printed on a label on the device's case or can be obtained from the
// Insteon app on your phone/tablet.
#define SmartBulb   "2F39E3"    // LED smart bulb - dimmable
#define Kitchen     "339EFC"    // Kitchen        - wall switch dimmer
#define Torch       "3608AB"    // Torch          - plug-in on/off module
#define Xmas        "2837FF"    // Xmas lights    - plug-in on/off module
#define Spare1      "360773"    // Spare          - plug-in on/off module
#define Bedroom     "3F8E35"    // Bedroom Fanlinc module - light and fan  

// Insteon Group numbers (scenes) for my Bedroom FanLinc. The scenes are needed for
// my Amazon Echo Dot to control the Fanlinc device.
// Scenes can be either on or off.
// ***** These should be replaced with the scene/group numbers of your scenes/groups *****
#define Light       "10"        // Fanlinc light
#define Fan1        "07"        // low speed
#define Fan2        "08"        // meduim speed
#define Fan3        "09"        // full speed

// Insteon commands
// for a device the on cmd includes the brightness, "11FF" -> full bright, "117F" -> half bright.
// for a device the off cmd includes the brightness, "1300" -> full off.
// for a scene the on/off cmds do not use the brightness setting, still must be present.
// Insteon commands are two bytes, Cmd1 and Cmd2. Cmd1 is the actual command, Cmd2 is the brightness level.
// If a device is dimmable then the on cmd uses Cmd2 to set the brightness, otherwise any value
// except zero will set it on.
// The off command always has Cmd2 set to zero.
// The fan section of a Fanlinc module uses Cmd2 to select light ("00") or fan ("03") status request.
// Commands to turn a Fanlinc fan on or off use extended command format.

// All Commands require a level (00-FF), ie; "11FF", "1300". On/off devices ignore the level, but
// it still must be there. Levels are only used by dimmers and Fanlinc
#define CmdOn           "11FF"    // command to turn on a scene or light, requires level (00->FF)
#define CmdHalf         "117F"    // command to turn a light on at half brightness, level = 7F
#define CmdOnFast       "12FF"    // command to fast turn on a scene or light
#define CmdOff          "1300"    // command to turn off a scene or light
#define CmdOffFast      "1400"    // command to turn off a scene or light
#define CmdBrighten     "1500"    // command to brighten by one step
#define CmdDim          "1600"    // command to dim by one step

// Fan Speed commands for FanLinc. 00->off, 01-7F->low, 80-FE->medium, FF->full.
// The levels defined by these commands will also work with dimmable lights.
#define CmdFanOff       CmdOff    // fan off
#define CmdFanLow       "113F"    // fan on low, any value from 01 to 7F
#define CmdFanMed       "1180"    // fan on medium, any value from 80 to FE
#define CmdFanHigh      CmdOn     // fan on high

// ***** Do not use these or change these *****
#define CmdStatus       "19"      // command to get status
#define Cmd2Lights      "00"      // second byte of status request for lights
#define Cmd2Fans        "03"      // second byte of status request for fans

// Special PLM messages
#define PlmClrBuf       "/1?XB=M=1"         // PLM command to clear the buffer
#define PlmGetBuf       "/buffstatus.xml"   // PLM command to get the buffer contents
#define PlmCmd          "/sx.xml"           // Send as PLM command, requires more data

// Buffer contents
// last byte is number of bytes in the buffer
// response to a command is formatted as: "0250" + DeviceId + "0F" + Cmdxx + "06" + "000...000" + number of bytes
// "0250" + DeviceId + Hub ID + "2x" + "00FF",  "2x" is Ack + hop cnt, indicates light is on  ('FF')
// "0250" + DeviceId + Hub ID + "2x" + "007F",  "2x" is Ack + hop cnt, indicates light is dim ('7F')
// "0250" + DeviceId + Hub ID + "2x" + "0000",  "2x" is Ack + hop cnt, indicates light is off ('00')
// "025C" + DeviceId + Hub ID + "2x" + "0000",  "2x" is Ack + hop cnt, indicates device is not present

// ESP8266 GPIO Pins used for switch inputs, GPIO15, ADC, RX and TX are not used.
// My Insteon Switch board has 10K pullups on all of these GPIO pins. Add switches to
// the ones you want to use.
#define Sw1   16
#define Sw2   14
#define Sw3   12
#define Sw4   13
#define Sw5   5
#define Sw6   4
#define Sw7   0     // this pin is used for programming, do not tie high or low
#define Sw8   2

#define NUMSWITCHES   8     // hardware supports 8 switches max

// twelve bits used for debounce. switch must be in the same state for 12 consecutive
// reads to be considered debounced. Change this if your switches are bouncier or less
// bouncy. Current value says switch must be in the same state for 12mS (1mS loop delay)
#define PINMASK   0x00000FFF

// Insteon device IDs are six characters in length
#define DEVIDLEN  6

// Unknow state for insteon devices
#define UnknownState  -1

// declare the action pointer type. The action pointer points to the action function invoked
// by a button press. The single parameter is a pointer to the TSwitch entry for the pressed
// switch
typedef void (*ActionPtr)(void *p);

// forward references to action functions
void actionToggle(void *p);     // reads status and then sends the 'on' or 'off' cmd to toggle the state
void actionOn(void *p);         // sends only the 'on' command
void actionOff(void *p);        // sends only the 'off' cmd
void actionFanSpeed(void *p);   // cycle through the fan speed settings

// this structure defines the parameters for one switch
typedef struct
{
  byte      pin;        // GPIO pin number
  int16_t   state;      // last known state of the Insteon device
  uint32_t  debounce;   // switch debouncer
  ActionPtr action;     // action to take when switch is pressed
  char      *devId;     // device ID or scene/group number as 'C' string
  char      *cmd2;      // cmd2 to send with status request  
  char      *cmdOn;     // on command string to send
  char      *cmdOff;    // off command string to send
} TSwitch;

// system parameters
typedef struct
{
  char *ssid;       // SSID of network to connect to
  char *passkey;    // network WPA passkey
  char *hub;        // IP address of the Insteon hub
  char *hubuser;    // user name for Insteon hub
  char *hubpass;    // password for Insteon hub

  // array of switches
  TSwitch sws[NUMSWITCHES]; // switch parameters
} TBox;

// Modify this table to add the device ID of your Insteon devices. Add the commands to send
// when the switch is pressed. The 'actionXxxx' is a pointer to the function that performs the
// desired action action when the switch is pressed.
// TSwitch.action == null indicates an unused/unassigned switch
// system initializer, change to values for your WiFi network and Insteon hub
//             SSID, WPA PassKey, IP adrs of Hub, Hub Username, Hub Password
TBox    box = {SSID, PASSKEY, HUBIP, HUBUSER, HUBPASSWORD,
// initializer for all the switches. fill in the switches that you want to use.
//          GPIO Pin, state, debounce, action, Device ID/Scene number, status cmd2, On cmd, Off cmd
               {{Sw1, UnknownState, 0, actionToggle,   Bedroom,   Cmd2Lights, CmdOn,   CmdOff},
                {Sw2, UnknownState, 0, actionToggle,   Bedroom,   Cmd2Lights, CmdHalf, CmdOff},
                {Sw3, UnknownState, 0, actionOn,       Bedroom,   Cmd2Lights, CmdDim,  CmdOff},
                {Sw4, UnknownState, 0, actionToggle,   Kitchen,   Cmd2Lights, CmdOn,   CmdOff},
                {Sw5, UnknownState, 0, actionFanSpeed, Bedroom,   Cmd2Fans,   CmdOn,   CmdOff},
                {Sw6, UnknownState, 0, actionOff,      Bedroom,   Cmd2Fans,   CmdOn,   CmdOff},
                {Sw7, UnknownState, 0, NULL,           Bedroom,   Cmd2Lights, CmdOn,   CmdOff},
                {Sw8, UnknownState, 0, NULL,           Fan3,      Cmd2Lights, CmdOn,   CmdOff}}};

// The hardware has two colums of four switches each arranged as;
// SW1 - SW5
// SW2 - SW6
// SW3 - SW7
// SW4 - SW8
// If you want the switches opposite each other to turn on and off one device then use two switches
// that are SWx and SWx + 4.
               
String    bfr;
char      cmdMsg[256];

//******************************************************************************
void setup()
{
  int i;
  TSwitch *psw;
  
  // make all switches inputs, ESP8266 does not support internal pullups
  pinMode(Sw1, INPUT);
  pinMode(Sw2, INPUT);
  pinMode(Sw3, INPUT);
  pinMode(Sw4, INPUT);
  pinMode(Sw5, INPUT);
  pinMode(Sw6, INPUT);
  pinMode(Sw7, INPUT);
  pinMode(Sw8, INPUT);
  
  Serial.begin(115200);   // Serial connection

  // connect to the WiFi network
  Serial.print("Connecting to ");
  Serial.println(box.ssid);
  
  WiFi.begin(box.ssid, box.passkey);   // WiFi connection

  while (WiFi.status()!= WL_CONNECTED)   // Wait for the WiFI connection completion
  {
    delay(500);
    Serial.print(".");
  }
  
  Serial.println();
  Serial.print("Connected to ");
  Serial.println(box.ssid);

  // try to get the current status of all the Insteon devices that are being used
  for (i = 0; i < NUMSWITCHES; i++)
  {
    psw = box.sws + i;
    if (psw->action)
    {
      updateState(psw);
      Serial.print("Button ");
      Serial.print(i + 1);
      Serial.print(" State: ");
      if (UnknownState == psw->state)
        Serial.println("Unknown");
      else
        Serial.println((0 == psw->state) ? "Off" : "On");
    }
  } //  for
} //  setup

//******************************************************************************
// Convert a String of hexadecimal characters to a signed 16 bit integer.
int16_t hexToInt(String s)
{
  char ch;
  uint16_t  x = 0;
  int   i;
  
  for (i = 0; i < s.length(); i++)
  {
    ch = s.charAt(i);
    x <<= 4;              // multiply x by 16
    if (ch >= '0' && ch <= '9')
      x |= (uint16_t)(ch - '0');
    else
    {
      ch &= 0xDF;           // convert to upper case alpha
      if (ch >= 'A' && ch <= 'F')
        x |= (uint16_t)(ch - 0x37);
    }
  } //  for

  return x;
} //  hexToInt

//******************************************************************************
// look for a status response message. message is prefixed with either;
// "0262" - cmd response, indicate last cmd sent
// "0250" - status response, indicates state of the device
// The reply message is a String in bfr.
// Reply message format; 0250 + devID + HubID + 2x + xx + status
// Reply message format; 025C + devID + HubID + 2x + xx + status
// x5C indicates device is not present (powered off)
// 2x is '2' for Ack and 0-F for hop count
// xx is any value
// status is 00-FF, where 00 is off and FF is on full bright

bool parseReply(String reply, TSwitch *psw)
{
  bool  b = false;
  int   idlen = strlen(psw->devId);
  int   msglen = 16 + idlen;
  int   index = 0;
  char  hdr[11];
  int   i;
  
  sprintf(hdr, "0250%s", psw->devId);
  while (index < reply.length() - msglen)
  {
    // look for starting header
    index = reply.indexOf(hdr, index);
    if (-1 != index)
    {
      // we found a header with matching device Id
      Serial.println();
      Serial.println(bfr.substring(index, index + idlen + 16));
      index += idlen + 14;
      String s = reply.substring(index, index + 2);

      psw->state = hexToInt(s);
      psw->state &= 0x00FF;
       
      b = true;
      break;
    }
  } //  while

  if (!b)
  {
    sprintf(hdr, "025C%s", psw->devId);
    index = 0;
    while (index < reply.length() - msglen)
    {
      // look for starting header
      index = reply.indexOf(hdr, index);
      if (-1 != index)
      {
        // we found a header with matching device Id
        // the device is not present
        Serial.println();
        Serial.println(bfr.substring(index, index + idlen + 16));
        // state is unknown, make it off
        psw->state = UnknownState;      // full 16 bit value
        b = true;
        break;
      }
    } //  while
  }

  return b;  
} //  parseReply

//******************************************************************************
// Status response from the device to the hub takes time. The hub is polled
// until a status response message is found in the buffer.
#define BfrDelay    100
void updateState(TSwitch *psw)
{
  char msg[25];

  for (int i = 0; i < 20; i++)
  {
    if (strlen(psw->devId) < DEVIDLEN)
    {
      // cannot get status of a scene
      psw->state = UnknownState;
      Serial.println();
      sprintf(msg, "Scene %s status is unknown", psw->devId);
      Serial.println(msg);
      break;
    }
    else
    {
      // clear PLM buffer
      sendPlmCmd(PlmClrBuf);
      delay(10);
  
      // get status of a device
      sendDeviceCmd(psw, CmdStatus);
      
      delay(BfrDelay);
        
      // get buffer
      sendPlmCmd(PlmGetBuf);
      if (parseReply(bfr, psw))
      {
        sprintf(msg, "State %04X, %s, Time: %dmS", psw->state,
               (UnknownState == psw->state) ? "Unknown" : (0 == psw->state) ? "Off" : "On", i * BfrDelay);
        Serial.println(msg);
        break;
      }
    }
  } //  for
} //  updateState

//******************************************************************************
// Send a message to the hub. The message is in the globla cmdMsg buffer.
int sendToHub(void)
{
  int httpCode = 404;
  
  if (WiFi.status()== WL_CONNECTED)   // Check WiFi connection status
  {
    HTTPClient http;                  // Declare object of class HTTPClient

//    Serial.println("Sending to hub");
//    Serial.println(cmdMsg);
    
    http.begin(cmdMsg);                             // Specify request destination
    http.addHeader("Content-Type", "text/plain");   // Specify content-type header
    httpCode = http.GET();                          // Send the request
    bfr = http.getString();                         // Get the response payload
    http.end();                                     // Close connection
  }
  else
  {
    Serial.println("Error in WiFi connection");   
  }

  return httpCode;
} //  sendToHub

//******************************************************************************
// Insteon uses two command formats, standard and extended. Most devices use the
// standard format. The fan part of a Fanlinc device uses extended format, the
// light part of a Fanlinc device uses standard format. The Cmd2 field of the
// TSwitch structure has "00" for devices that uses standard format and a value
// of "03" for devices that require extended format. A status request is always
// send using standard format
void stdCmd(TSwitch *psw, char *cmd)
{
  if (0 == strcmp(cmd, CmdStatus))
  {
    // the get status cmd uses the cmd2 byte from the TSwitch structure
    sprintf(cmdMsg, "http://%s:%s@%s:%s/3?0262%s0F%s%s=I=3", 
            box.hubuser, box.hubpass, box.hub, HTTPPORT, psw->devId, cmd, psw->cmd2);
  }
  else
  {
    sprintf(cmdMsg, "http://%s:%s@%s:%s/3?0262%s0F%s=I=3", 
            box.hubuser, box.hubpass, box.hub, HTTPPORT, psw->devId, cmd);
  }
} //  stdCmd

//******************************************************************************
// Extended commands use a flags byte of "1F" and fourteen extra bytes appended
// to the standard command. For the fan section of a Fanlinc the first byte of
// the extra fourteen is "02", indicates cmd is for the fan.
// flags byte changes, 0F -> 1F
// add 02 to the end of the message for device type (02 -> fan)
// add 13 bytes of 00 to the end of the message
void extCmd(TSwitch *psw, char *cmd)
{
  sprintf(cmdMsg, "http://%s:%s@%s:%s/3?0262%s1F%s0200000000000000000000000000=I=3", 
          box.hubuser, box.hubpass, box.hub, HTTPPORT, psw->devId, cmd);
} //  extCmd


//******************************************************************************
// Use the Cmd2 field to determine the format to use for sending a command. Get
// status is always sent using standard format.

// Status requests are always send using standard format. The fan section of a
// Fanlinc device require on/off commands to use extended format. The cmd itself
// and the cmd2 field of the TSwitch structure determeine the format to use.
int sendDeviceCmd(TSwitch *psw, char *cmd)
{
  // create cmd message in the global cmdMsg buffer
  if ((0 == strncmp(cmd, CmdStatus, 2)) || (0 == strcmp(psw->cmd2, Cmd2Lights)))
  {
    stdCmd(psw, cmd);
  }
  else
  {
    extCmd(psw, cmd);
  }
  
#ifdef DEBUG
  Serial.print("Cmd: ");
  Serial.println(cmdMsg);
#endif
  return sendToHub();
} //  sendDeviceCmd

//******************************************************************************
// Create a PLM style command and then send it to the hub.
void plmCmd(char *devId, char *cmd)
{
  char cmdbfr[25];
  
  sprintf(cmdbfr, "/sx.xml?%s=%s", devId, cmd);
  sendPlmCmd(cmdbfr);
} //  plmCmd

//******************************************************************************
// An alternative format to send commands to the hub. Used mainly for commands 
// that manipulate the PLM of the hub and not Insteon devices.
int sendPlmCmd(char *cmd)
{
  // create the command message to send
  sprintf(cmdMsg, "http://%s:%s@%s:%s%s", box.hubuser, box.hubpass, box.hub, HTTPPORT, cmd);
  return sendToHub();
} //  sendPlmCmd

//******************************************************************************
// Send a scene command using the short form of the standard command. 
int sendSceneCmd(TSwitch *psw, char *cmd)
{
  char cb[3];

  // we only want the first two bytes of the cmd
  cb[0] = cmd[0];
  cb[1] = cmd[1];
  cb[2] = '\0';

  // create the command message to send, use the short form, cmd is first, followed
  // by scene number. scenes can only be on or off, no level
  sprintf(cmdMsg, "http://%s:%s@%s:%s/0?%s%s=I=0", box.hubuser, box.hubpass, box.hub, HTTPPORT, cb, psw->devId);

#ifdef DEBUG
  Serial.print("Scene cmd: ");
  Serial.println(cmdMsg);
#endif
  return sendToHub();
} //  sendSceneCmd

//******************************************************************************
// Get the PLM buffer and return true if the command was accepted.
bool cmdAccepted(char *hdr)
{
  bool accepted = false;
  int pos;

  // check for command accepted by the device
  sendPlmCmd(PlmGetBuf);
#ifdef DEBUG
  Serial.print(bfr);
#endif
  pos = bfr.indexOf(hdr);
  if (-1 != pos)
  {
#ifdef DEBUG
    Serial.print(pos);
    Serial.print(", ");
    Serial.print(hdr);
    Serial.print(", Found: ");
    Serial.println(bfr.substring(pos));
#endif
    // command was accepted
    accepted = true;
  }

  return accepted;
} //  cmdAccepted

//******************************************************************************
// Reads the current state of the device and sends the command to change the
// state. Be patient, the hub takes a few seconds to get status from the devices.
// This can only be used with devices. Repeat the command until the device
// reports the command was accepted.
void actionToggle(void *p)
{
  TSwitch *psw = (TSwitch *)p;
  uint16_t target = hexToInt(psw->cmdOn);

  target &= 0x00FF;
  
  updateState(psw);

  // repeat ten times or until command is accepted by the device
  for (int i = 0; i < 10; i++)
  {
    sendDeviceCmd(psw, (target == psw->state) ? psw->cmdOff : psw->cmdOn);

    delay(100);
    
    // check for command accepted by the device
    if (cmdAccepted("0262"))
      break;
  } //  for
} //  actionToggle
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
void loop()
{
  int i;
  TSwitch *psw;
  
  for (i = 0; i < NUMSWITCHES; i++)
  {
    psw = box.sws + i;
    debouncer(psw);
  }

  delay(1); 
} //  loop
